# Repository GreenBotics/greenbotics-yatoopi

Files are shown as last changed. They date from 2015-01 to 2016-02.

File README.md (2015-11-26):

## yatoopi (pronounced 'jɑ-tu-pe' )



> aka: Yet another aquaponics project 

## Overview :

Here you will find all the files for this project:
cad, documentation, blog etc

### The aims are :

- open source
- low cost
- somewhat beginner friendly (I am one too)
- maximising re-use (for example I have a box
of 10 or so relatively small dc motors I intend to reuse for various purposes).
- use 3d printing "in a somewhat inteligent manner" : 
this means using it in a lot of cases where repeatable, cheap , reproductible, small /med run
of parts are needed, but not "forcing" its use either
- explore what is possible without massive amounts of store-bought equipment
- not reinvent the wheel whenever possible : I explore, test, modify, other people's
designs whenever possible
- "eco friendly"
- "self sufficient"
- note the quotes around the last two...

FYI , this whole thing is still in the very early stages, but for ONCE, I really
do not want to do documentation 2 years after I am fed up with a project: remember: 
"release early, release often, and DOCUMENT you efforts are least a bit".

## Sub pages etc

[testing](../master/docs/testing.md)

## Grow bed etc

 - the grow bed is build with wood and 3d printed parts
 - while not strictly necessary (you can build grow beds without 3d printing), 
 all the parts used either makes building easier, cheaper, or more practical.
 Also, they offer some esthetic/security benefits (rounded corners etc)
 
 Another important aspect of 3d printed parts: they can be build identically ,
 regardless of your tooling, as long as you have a 3D printer.
 
## cad files (3d printed)

  - for the [grow bed](../master/cad/growbed) (printed corners, assembly helpers)
  - for the [piping](../master/cad/piping) (outflow/drain and media guard )

assembly guides, pictures etc comming soon

## Author:

Mark 'kaosat-dev' Moissette

## LICENSE

GPL until I come up with something better, possibly public domain 

[The GLP License (GPL)](https://github.com/GreenBotics/Automaton/blob/master/LICENSE)

- - -

experimental (http://github.com/badges/stability-badges)

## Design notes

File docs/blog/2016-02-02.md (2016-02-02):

------------------------------------

Title:  Lift-off! Aka: plants are growing!

Author: Mark Moissette 

Date:   2016-02-02 

------------------------------------

##Lift-off!

Planting the (lettuce) seeds took place last week on the 2016-01-27 

![After seeding]
(https://raw.githubusercontent.com/GreenBotics/yatoopi/master/docs/blog/2016-02-02/2016-02-02_00.jpg)

It was done using the following layout

| Lettuce Name | Symbol |
| --- | --- |
| lamb's lettuce | L |
| curly lettuce | C |
| Romaine | R |
| Frisee | F |
| basilicum | B |
| parsley | P |

|---| A | B | C | D | E | F | G | H |
|---|---|---|---|---|---|---|---|---|
| 1 | L | L | L | R | R | C | P | P | 
| 2 | L | L | L | R | R | | | | 
| 3 | L | L | L | R | R | | | | 
| 4 | L | L | L | R | R | C | B | B | 

### Good news :

* The romaine already sprouted after less than **4** days. 
* Power consumption is hovering at around **115 W** for the system (lamps + water pump + air pump),
so this means this can possibly be covered by even a simple solar pannel setup

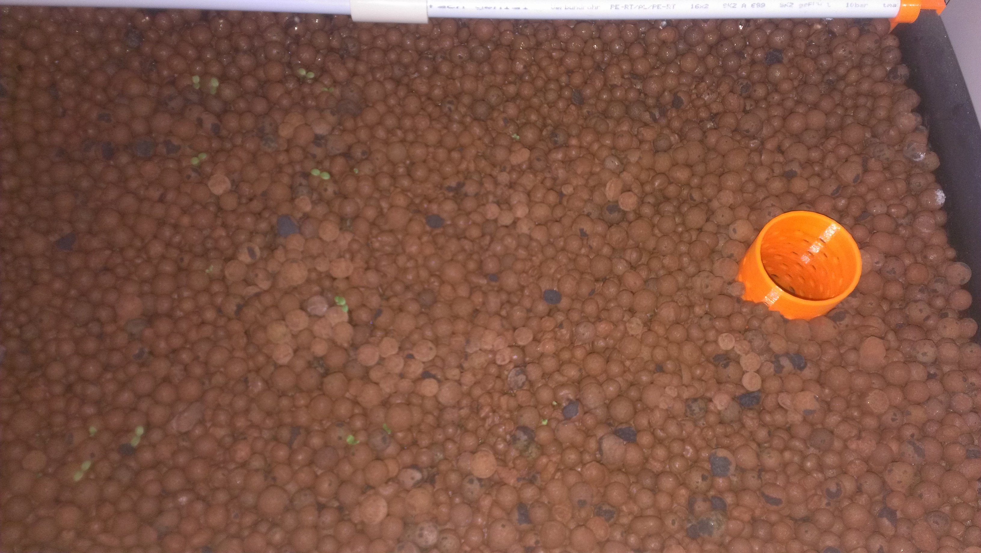
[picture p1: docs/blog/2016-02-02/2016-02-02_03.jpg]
6 days after (in bad lighting

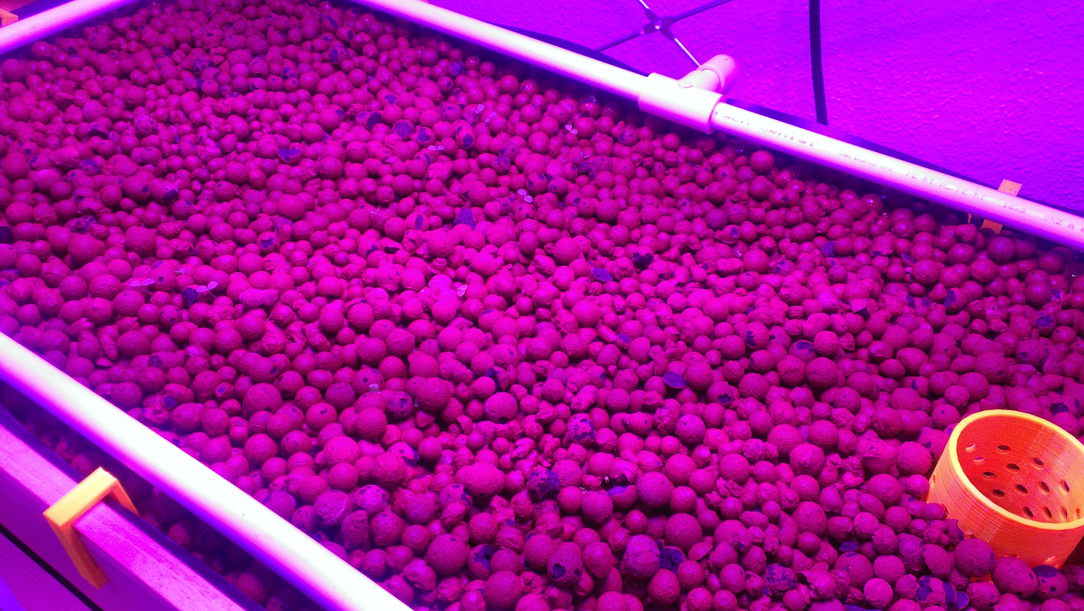
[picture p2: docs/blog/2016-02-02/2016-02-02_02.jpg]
6 days after (the leaves are there, but barely visible


### The less good news: 

* I still have not completed the automated monitoring system (temperature, humidity, water depth in tank, wide angle camera), 
so detailed environemental tracking will not be available from the start , but given that this is an indoor setup, variations 
in the parameters should be minimal
* I have also attempted to install a basic Raspberry Pi + Webcam setup to have some nice remote viewing/timelapse capabilities, but the **very** cheap webcams I have , have very limited view angle, which makes them close to useless

### Next steps:

* watching things grow and going "this rocks, what an amazing level of growth" everyday !
* I have started to look into reusing an old ultrasonic sensor I have for the fishtank water level measurement 
* The [Arducam](http://www.arducam.com/)[ + Esp8266 combo](http://www.arducam.com/tag/arducam-esp8266/) also seems **very** interesting to say the least (even more so as you can more easilly change lenses, switching to a wide angle one) than with a basic webcam / RaspiCam
* I also **DO** intend to finish a basic version the monitoring setup's software side as soon as possible (whenever that might be)

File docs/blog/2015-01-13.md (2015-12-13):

## Airlift pump, first success

#### 2015 Jan 13

So , finally got around to testing of **model A0** *

- raw data
  0.10 L in 6 mins 28,37s 

  ie 0.10L in 388.37s aka 0.015 / min aka 0.92L /h
  
  //old stuff : 6.47283333 mins => 0.0154 L * min-1

- notes: 
  first sucessfull & reproducible test, other air pump (P1 , 100L/H) seems to be half dead
  (ie even attaching a simple bubbler and putting it in water hardly produces any air bubbles)

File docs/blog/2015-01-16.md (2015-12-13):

##  Airlift pump, continued

#### 2015 Jan 16

#### Seperation of concerns etc

one very interesting aspect of airlift pumps is that it allows me to test
their 2 "parts" seperatly:

- the air pump
- the airlift system / pressure chamber

For the first phase of testing, I decided to use commercial (aquarium) air pumps
and see what results I can get : this allows a validation of the airlift system
without worrying about insuficient air pressure.

aka, science : it makes sense !

I tested with 16 mm pipes and the printed ##XXXX

Tested with 200L/h Eheim air pump

Result : 0.1 L in 2 mins 18.22 seconds 

So 0.1 L in 138.22 s aka 0.043 L / min aka 2.6 L per hour

Not so great in absolute terms but keep these things in mind : 

- the water is lifted 60 cm withouth any problems
- the whole plumbing is a prototype which means the joints are waterproof etc

#### Lobe pumps etc:

I also started researching some of the formulas behind lobe pumps
and creating the basics of a parametric design in .

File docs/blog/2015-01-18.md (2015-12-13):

## Airlift pump, continued (3)

#### 2015 Jan 18

I tested with 6 mm tube and the printed ##XXXX 

Tested with 200L/h Eheim air pump with **both outlets
set to 50l/h** : I had to reduce it to minimal levels
as anything over 50 L/h would result in a lot of bubbles but no water being pumped.

Result : 0.05 L in 3 mins 28.46 seconds 

So 0.05 L in 208.46 s aka 0.015 L / min aka 0.86 L per hour

...worst one so far

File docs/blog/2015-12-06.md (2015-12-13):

##Upgrades, reboot etc

After a big failure last summer (most plants died) the grow system never really took off:

So here are steps to get everything (finally ?) going :

- switch to a more powerfull, WATER pump : airlift pumps are really great, but 
are not good enough with so little water depth (around 25 cm max in the current setup)
and are thus too sensitive to water level variations

- actually install a bell (or other) symphon system : this means changing most of the 3d printed plumbing

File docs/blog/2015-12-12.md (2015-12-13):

##Bell syphon...or not

Verdict after running the bell syphon to a lot of different tests:
 it "works"...sorta:
- extremely finicky
- very limited range of flow rates that correctly triggers it
- outwards flow with this size is never sufficient : a inflow strong enough
to trigger the syphon is also also too much to reduce the water level in the container

This means ...Back to the drawing board!
A more mechanical system, but a less sensitive one seems a better bet

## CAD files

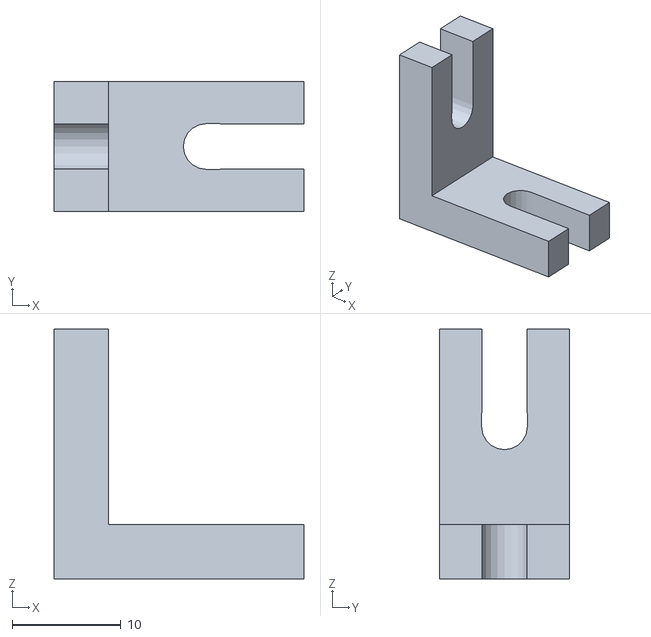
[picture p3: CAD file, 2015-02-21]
cad/growbed/assembly-helpers/BoxAssemblyHelpers.0.0.1.stl
23.0 x 12.0 x 23.0

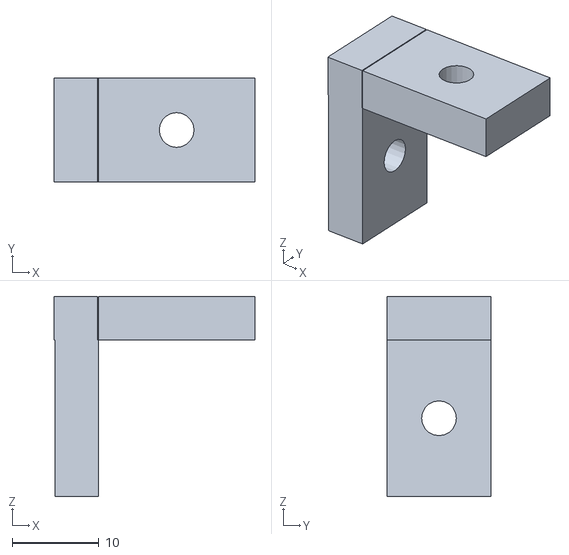
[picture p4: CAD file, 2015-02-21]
cad/growbed/assembly-helpers/BoxAssemblyHelpers.stl
23.1 x 12.0 x 23.0

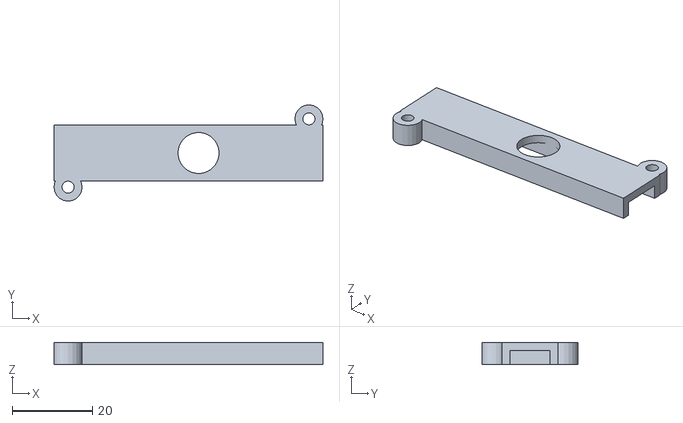
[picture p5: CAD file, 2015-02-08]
cad/accessories/webcam-holder/webcam-holder-top-0.0.1.stl
67.0 x 24.0 x 5.50

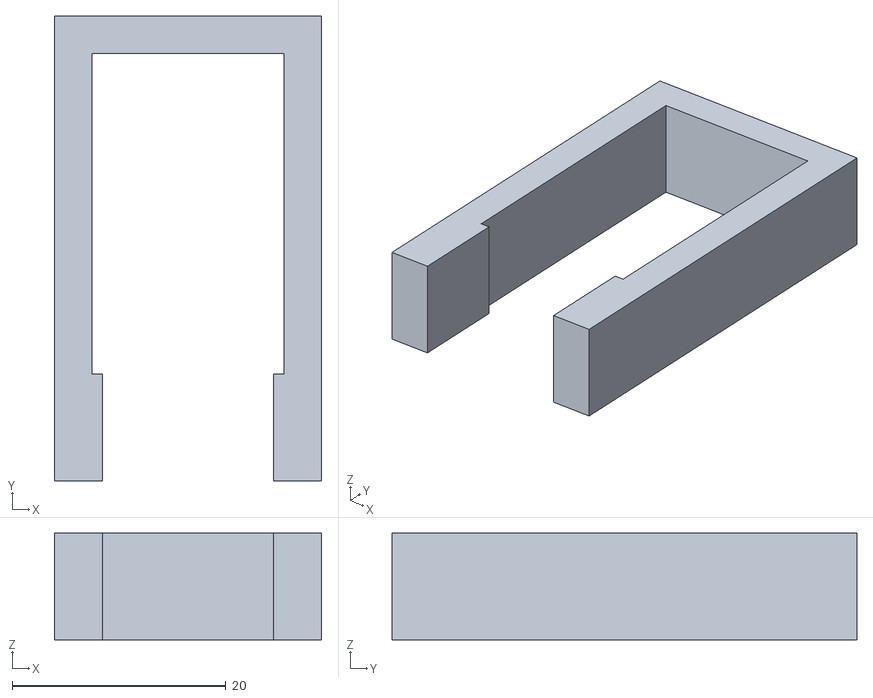
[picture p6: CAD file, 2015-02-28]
cad/growbed/bed-clips/bed-clips.0.0.1.stl
25.0 x 43.5 x 10.0

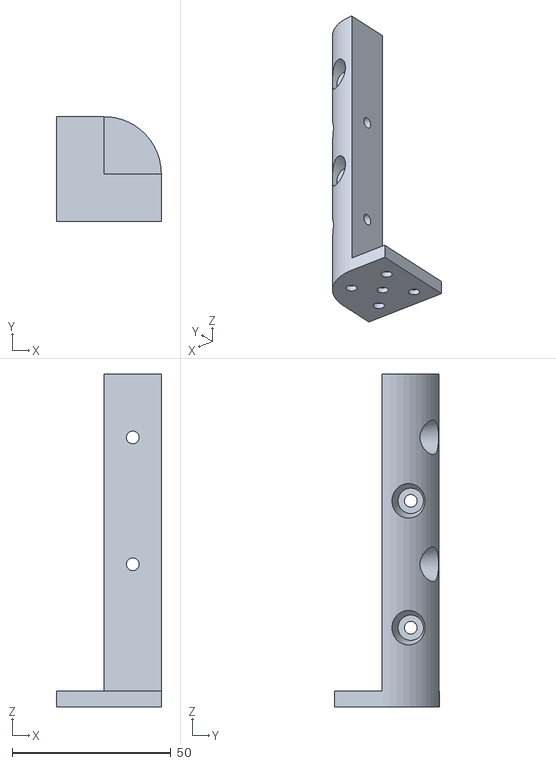
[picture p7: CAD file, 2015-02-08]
cad/growbed/bed-corners/aquaponics-bed-corner-0.0.1.stl
33.0 x 33.0 x 105.0

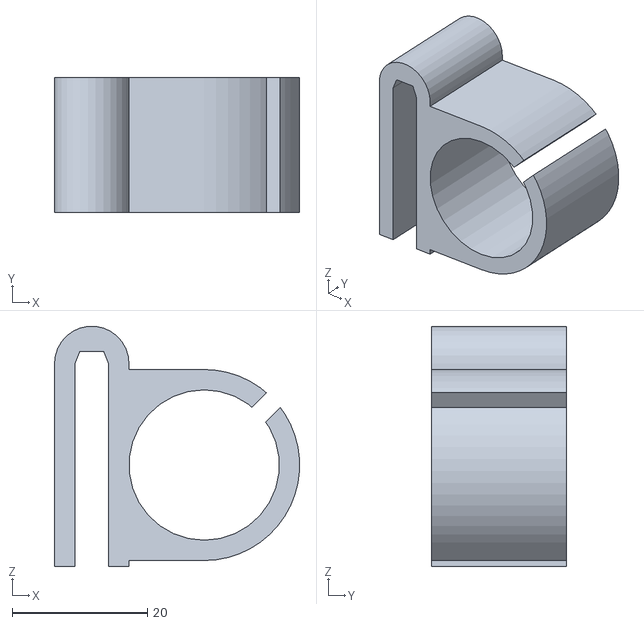
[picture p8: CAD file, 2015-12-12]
cad/piping/aquarium-mounts/sideTubingHolder-m22-0.0.2.stl
36.2 x 20.0 x 35.5

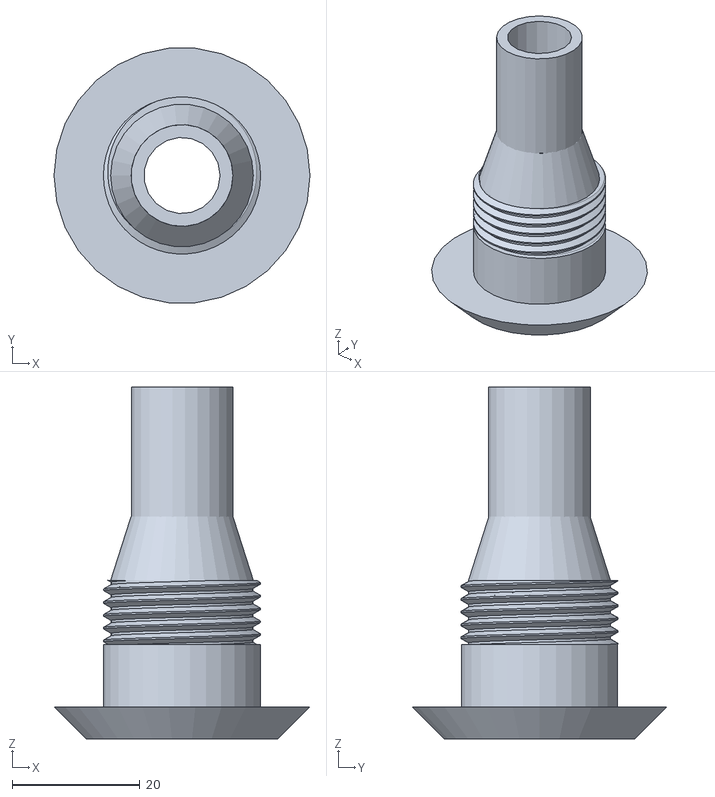
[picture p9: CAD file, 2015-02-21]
cad/piping/hydroponic-drain/hydroponic_drain_0.0.4.stl
40.0 x 39.8 x 55.0

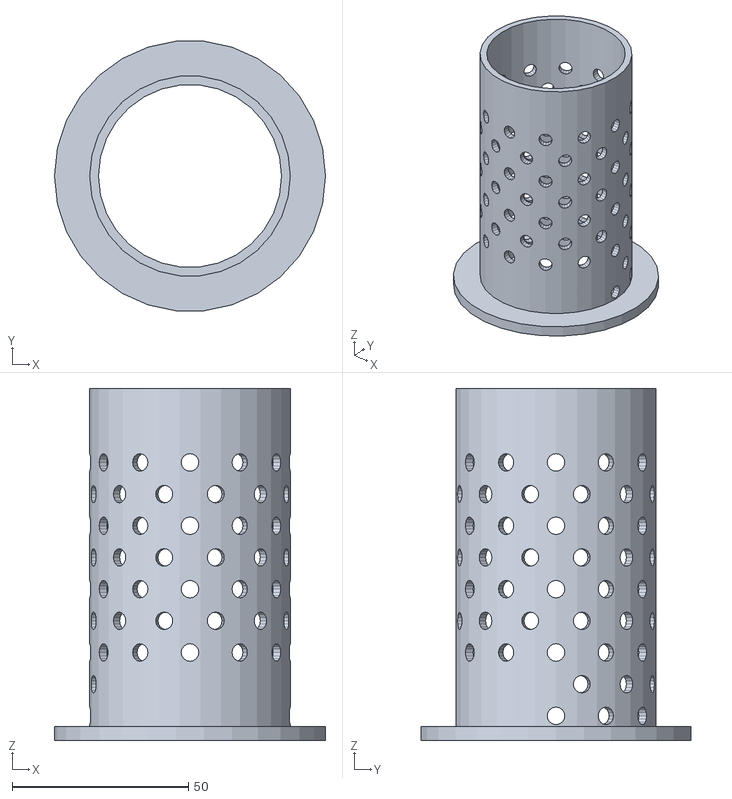
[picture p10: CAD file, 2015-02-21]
cad/piping/media-guard/MediaGuard.0.0.1.stl
77.0 x 76.6 x 100.0

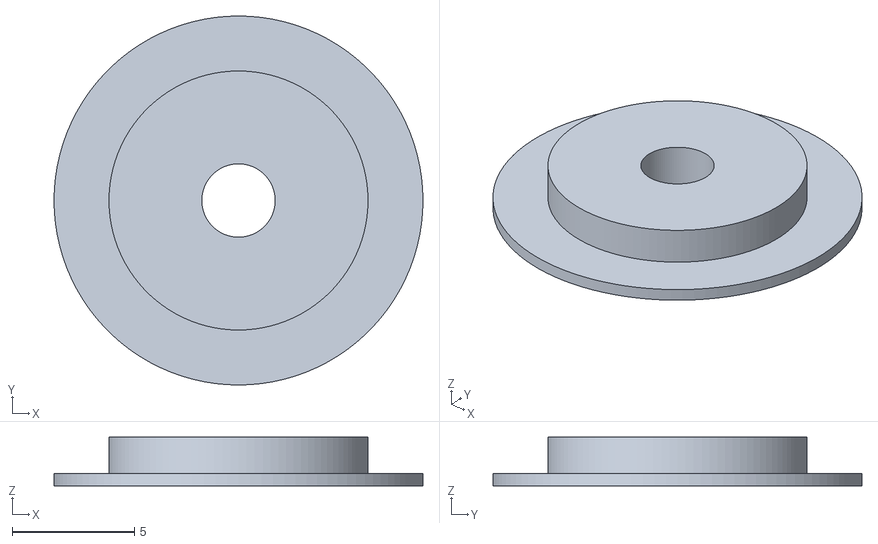
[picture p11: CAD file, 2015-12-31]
cad/piping/syphon-system/custom_syphon_bucket_out_3mm.stl
15.1 x 15.1 x 2.00

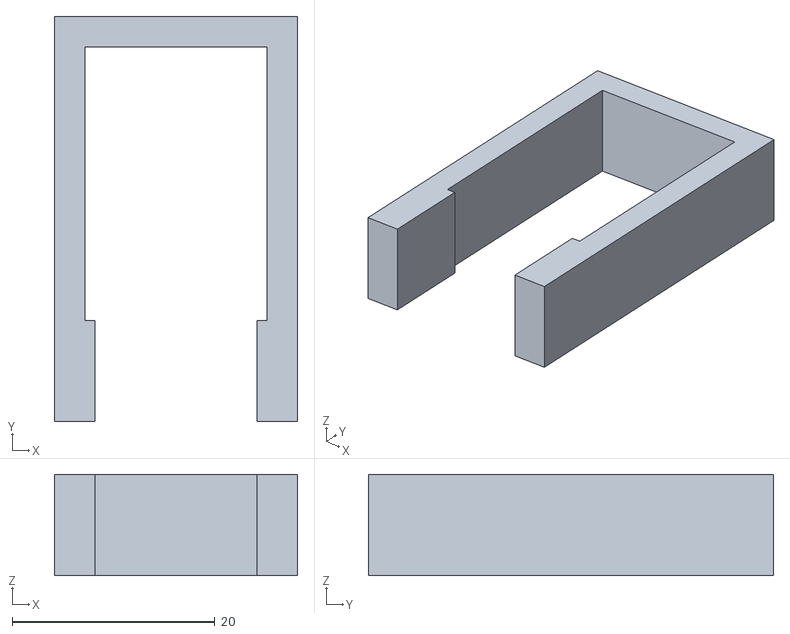
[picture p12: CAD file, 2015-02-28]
cad/growbed/bed-clips/bed-clips.stl
24.0 x 40.0 x 10.0

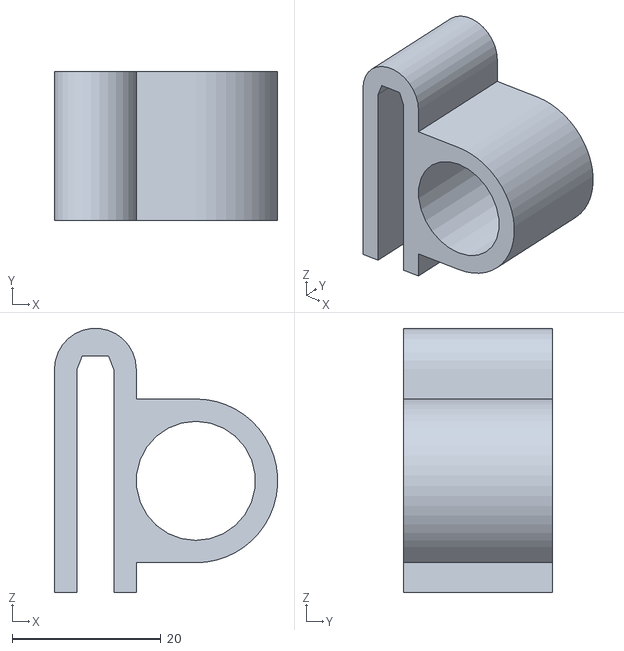
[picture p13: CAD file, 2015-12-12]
cad/piping/aquarium-mounts/sideTubingHolder-m16-0.0.1.stl
30.0 x 20.0 x 35.5

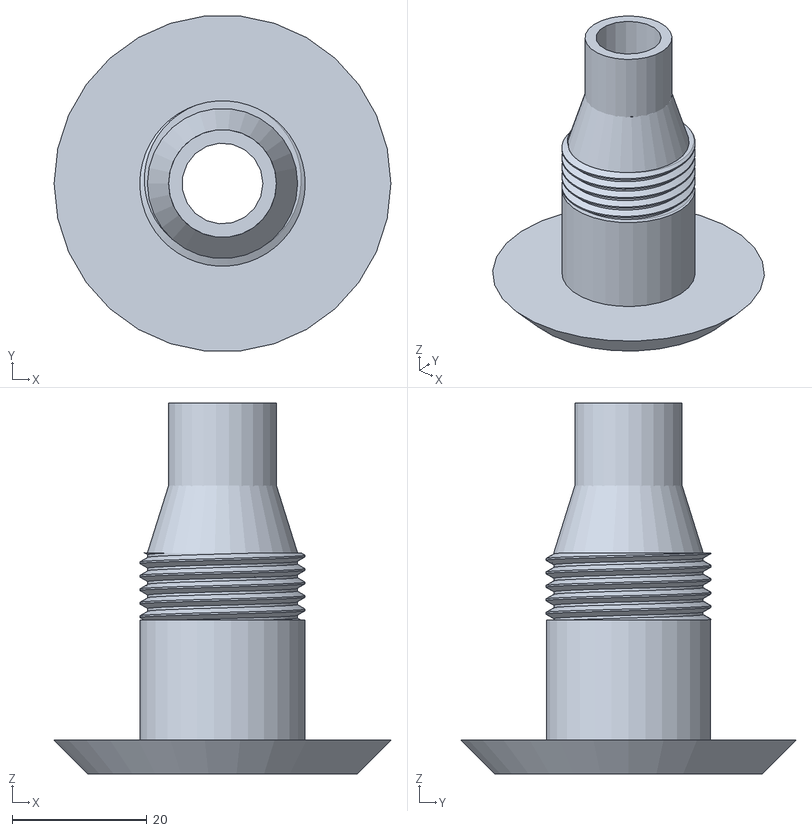
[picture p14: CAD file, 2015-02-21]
cad/piping/hydroponic-drain/hydroponic_drain_0.0.5.stl
50.0 x 49.7 x 55.0

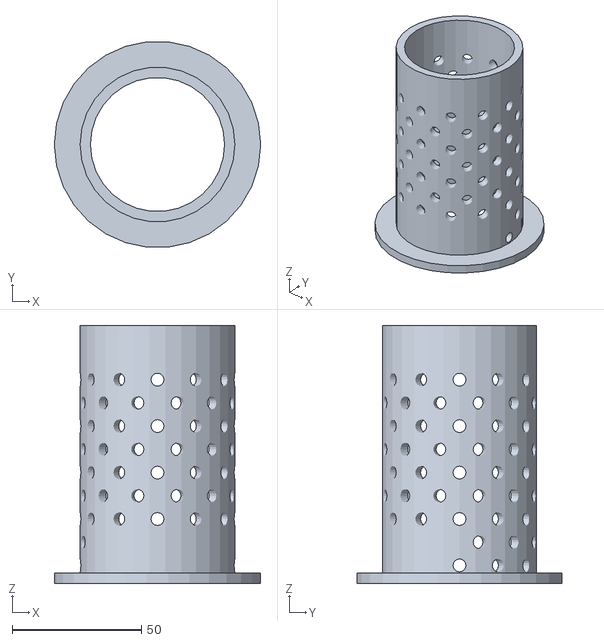
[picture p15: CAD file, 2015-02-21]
cad/piping/media-guard/MediaGuard.stl
80.0 x 79.6 x 100.0

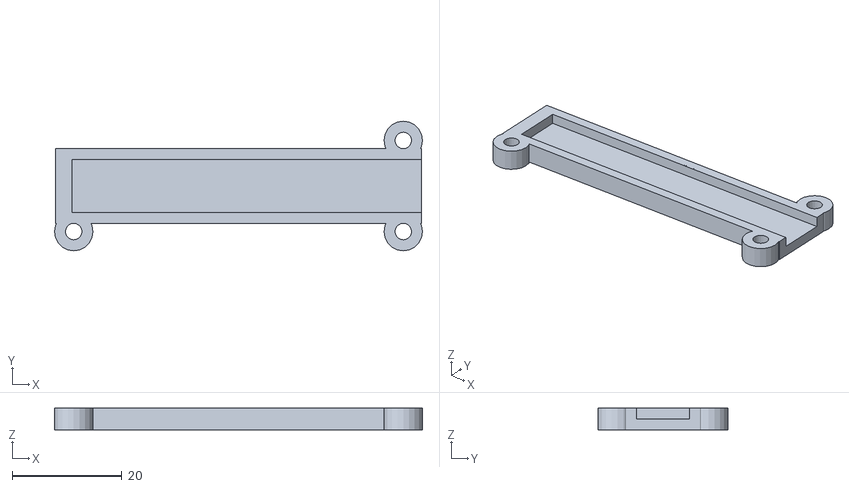
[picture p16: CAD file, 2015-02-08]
cad/accessories/webcam-holder/webcam-holder-bottom-0.0.2.stl
67.0 x 23.6 x 3.98

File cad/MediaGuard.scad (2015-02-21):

// Media guard , to prevent media (clay pellets etc) + roots
//from clogging the outflow

mediaGuard();

module mediaGuard(height=100,innerDia=52,wallSize=4, baseLip=10, baseLipHeight=4, res=30){
  fullDia = innerDia+wallSize*2;
  fudge= 0.1;
  
  bottomNoWaterZoneHeight = 2;//how heigh is the zone withouth holes at the base of the guard
  orientedWaterZoneHeight = 18; 
  orientedWaterZoneAlign  = "front"; //can be "front","back"
  topNoWaterZoneHeight = 10;
  
  holesDia = 5;
  holesRes = 8;
  vertHolesDist = holesDia + 4;
  
  radHolesNb = 12;
  
  module baseHole(length = fullDia){
    rotate([0,90,0]) cylinder(r=holesDia/2,h=length,$fn=holesRes,center=true);
  }
  
  module holes(){
    fullHolesZoneHeight = height - orientedWaterZoneHeight - bottomNoWaterZoneHeight - topNoWaterZoneHeight;
    verHolesNb         = (fullHolesZoneHeight-vertHolesDist) / vertHolesDist;
    layerRot  = (360 / radHolesNb)*1.5;// how much do we rotate holes for each "hole layer" so they are not aligned
    
    //for oriented holes region
    orientedHolesVerNb = orientedWaterZoneHeight / vertHolesDist;
    orientedHolesLength= fullDia/2;
    orientedHolesOffset = orientedWaterZoneAlign == "front" ? fullDia/2 : -fullDia/2;
    orientedHolesLayerRot  = (360 / radHolesNb)*0.5;// how much do we rotate holes for each "hole layer" so they are not aligned
    echo("orientedHolesVerNb",orientedHolesVerNb,"verHolesNb",verHolesNb,"orientedHolesOffset",orientedHolesOffset);
    
    
    //main hole
    translate([0,0,-fudge/2]) cylinder(r=innerDia/2,h=height+fudge,$fn=res);
    
    //all sided holes
    for( j = [0 : verHolesNb ] )
    {
      for ( i = [0 : radHolesNb/2] )
      {
          rotate( i * 360 / radHolesNb + ( j * layerRot ), [0, 0, 1])
          
          translate([0, 0, bottomNoWaterZoneHeight+orientedWaterZoneHeight+holesDia+j*vertHolesDist])
          baseHole();
      }
    }
    
    //oriented (one sided) holes
    for( j = [0 : orientedHolesVerNb-1 ] )
    {
      for ( i = [0 : radHolesNb/2] )
      {
          rotate( i * 360 / radHolesNb + ( j * orientedHolesLayerRot ), [0, 0, 1])
          translate([orientedHolesOffset, 0, bottomNoWaterZoneHeight+holesDia+j*vertHolesDist])
          baseHole(orientedHolesLength);
      }
    }
    
    
  }
  
  difference(){
        union(){
          cylinder(r=fullDia/2,h=height,$fn=res);
          cylinder(r=(fullDia+baseLip*2)/2, h=baseLipHeight);
        }
    holes();
  }
  
  
  
}

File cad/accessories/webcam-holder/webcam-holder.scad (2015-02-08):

//webcamHolder(side="bottom");
webcamHolder(side="top");



module webcamHolder(side="top"){
  fudge = 0.01;
  length = 61;
  width  = 8;
  height = 3.95;
  wallThickess = 2;
  innerClearance= 0.8;
  innerClearanceTopBottom = 0;
  
  camOpticsDia = 10.2;
  camOpticsOffset=28;
  
  mountHolesDia = 2.1;
  mountHoleStartOffset= 7.6;
  mountHolesEndDist = 4;
  
  pcbThickness         = 2;
  pcbFootOutlineHeight = 0.5;
  pcbFootOutlineWidth  = 0.5;
  
  extMountDia = 3;
  
  fullLength = length + ( wallThickess + innerClearance ) *2;
  fullWidth  = width  + ( wallThickess + innerClearance ) *2;
  fullHeight = height + ( wallThickess + innerClearanceTopBottom ) *2;
  
  innerLength = length + ( innerClearance ) *2;
  innerWidth  = width  + ( innerClearance ) *2;
  innerHeight = height + ( innerClearanceTopBottom ) *2;
  
  pcbFootWidth  = width   - pcbFootOutlineWidth*2;
  pcbFootLength = length - pcbFootOutlineHeight*2;
  pcbFootHeight = 3;
  
  echo("fullHeight",fullHeight);
  
  res=50;
  
  
  difference(){
  
    union(){
    
      difference(){
        cube(size=[fullLength, fullWidth, fullHeight],center=true);
        translate([wallThickess, 0, 0])  cube(size=[innerLength+wallThickess, innerWidth, innerHeight],center=true);
        
        translate([length/2-camOpticsOffset, 0, -fudge]) #cylinder(r=camOpticsDia/2,h=fullHeight/2+fudge,$fn=res);
      };

      
      //pcb outline "feet"
      /*translate([0,0,-innerHeight/2+pcbFootOutlineHeight/2]) 
      difference(){
        cube(size=[length, width, pcbFootOutlineHeight],center=true);
        cube(size=[pcbFootLength, pcbFootWidth, pcbFootOutlineHeight],center=true);
      }
      translate([0,0,-innerHeight/2+pcbFootOutlineHeight/2+pcbThickness]) 
      difference(){
        cube(size=[length, width, pcbFootOutlineHeight],center=true);
        cube(size=[pcbFootLength, pcbFootWidth, pcbFootOutlineHeight],center=true);
      }
      */
      
      
      //bolt mount stuff
      translate([30,(fullWidth+extMountDia)/2,0]) mount( od= extMountDia+wallThickess*2, id=extMountDia, h=fullHeight);
      translate([30,-(fullWidth+extMountDia)/2,0]) mount( od= extMountDia+wallThickess*2, id=extMountDia, h=fullHeight);
      
      translate([-30,-(fullWidth+extMountDia)/2,0]) mount( od= extMountDia+wallThickess*2, id=extMountDia, h=fullHeight);
    }
  
    //TODO: UGH openscad old version : no real variables, asignments etc 
    //cutoffset = -3;
    if(side == "top")
    {
      translate([0,0,-3]) #cube([100,50,6],center=true);
    }
    if(side == "bottom")
    {
      translate([0,0,3]) #cube([100,50,6],center=true);
    }
    
    
  }
  
  //pcb foot : should not be cut in half
  if(side == "top"){
    translate([-length/2+1.5,0,+pcbFootHeight/2]) 
    cube(size=[3, innerWidth, pcbFootHeight],center=true);
  }
}


module mount(od=5, id=3, h=10,res=20){

  difference(){
      cylinder(r=od/2,h=h,$fn=res,center=true);
      cylinder(r=id/2,h=h,$fn=res,center=true); 
  }

}

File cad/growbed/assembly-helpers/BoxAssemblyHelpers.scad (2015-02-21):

// An L shaped wooden box assembly / screwing helper

assemblyHelper();

module assemblyHelper(plankThickness=18,screwDia=4,wallSize=4,thickness=5){

  height = plankThickness;
  width    = wallSize*2 + screwDia;
  fudge= 0.1;
  
  module side(){
      difference(){
        translate([height/2-thickness/2,0,thickness/2]) cube([height+thickness,width,thickness],center=true);
        
        
        translate([height/2,0,0]) 
          hull(){
            cylinder(r=screwDia/2+fudge,h=thickness+fudge,$fn=20);
            translate([0,-(screwDia+fudge)/2,0])cube([height/2,screwDia+fudge,thickness+fudge]);
          }
      }
  }
  
  rotate([0,-90,0]) union(){
    side();
    rotate([0,90,0]) translate([0,0,-thickness]) side();
    //translate([-thickness-0.1,-width/2,0]) cube([thickness,width,thickness+fudge]);
  }
}

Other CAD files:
cad/accessories/webcam-holder/webcam-holder-top.stl
cad/growbed/bed-corners/aquaponics-bed-corner-0.0.2.stl
cad/piping/syphon-system/custom_syphon_bucket_out_1mm.stl
cad/growbed/bed-corners/aquaponics-bed-corner.stl
cad/growbed/bed-clips/bed-clips.scad
cad/accessories/webcam-holder/webcam-holder-top-0.0.1-test.stl
cad/accessories/webcam-holder/webcam-holder-top-0.0.2.stl
cad/growbed/bed-corners/aquaponics-bed-corner.scad
cad/piping/aquarium-mounts/aquariumMounts.scad
cad/piping/aquarium-mounts/cornerTubingHolder-0.0.1.stl
cad/piping/aquarium-mounts/sideTubingHolder-m22-0.0.1.stl
cad/piping/hydroponic-drain/hydroponic_drain.scad
cad/piping/hydroponic-drain/hydroponic_drain_nut.scad
cad/piping/hydroponic-drain/hydroponic_drain_nut_0.0.5.stl
cad/piping/hydroponic-drain/hydroponic_stand_pipe.scad
cad/piping/hydroponic-drain/threads.scad
cad/piping/media-guard/MediaGuard.scad
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

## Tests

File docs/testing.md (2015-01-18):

Pump and airlilft designs testing
=================================

###Goals

  For now , for an indoor, relatively small setup : 
  
  - 60 L aquarium, fish species not decided yet, could be too small for Tilapias
  - 80 x 40 X 10 aprox grow bed, home built, wood & 3d printed parts: more on this later
  - two 13w neon tubes (bathroom variety, will post more specs)
  - aquarium is 60 cm below the grow bed, so any pumping system needs to be able to lift water up to that height *at least*

#Pumps

Bought Pumps 
------------

- 3W air pump  : 60L / h (id: P0)
- 6W air pump  : 100L /h (id: P1) **KO**
- 3.5W air pump: 200L /h (id: p2) 

Pump Id  |  Pump type   |  Power rating(W) | Works? | Air/Water flow L/h | Price (e) | ref 
---------|--------------|----------------  |--------| -------------------| --------- | ---
P0       |    air       |  3               | yes    |   60               | N/A       | N/A
P1       |    air       |  6               | no     |   100              | N/A       | N/A
P2       |    air       |  3.5             | yes    |   200              | 30        | N/A

Built pumps
-----------

- nothing conclusive so far, work in progress
  
Airlift pump designs
---------------

  > **What is an airlift pump ? **
  > http://en.wikipedia.org/wiki/Airlift_pump 

Found following designs:

- Conduit with Hole 
by 3Dponics http://www.thingiverse.com/thing:400341 (id: A0)
- Airlift pump - air powered water pump
by gswatts, http://www.thingiverse.com/thing:515591 (id: A1)
- Parametric Airlift Water Valve
by relet http://www.thingiverse.com/thing:14230 (id: A2)
- Water pump driven by air
by bqzero http://www.thingiverse.com/thing:609739 (id: A3)

  > **Note:**
  > I do not support, condone the policies of, or like Makerbot & thus Thingiverse in any form or way,
  > but sadly, I was not able to find designs in any other 3d printable design repositories...

So to recap (tables are easier to read or something ?)

Airlift design Id  |  Airlift design name                       | design link   | Designer |  License  |
------------------ | --------------------------------------     | --------------| -------  |  -------- |
A0                 |  Conduit with Hole                         | http://www.thingiverse.com/thing:400341 |  3Dponics | CC-BY-NC-SA
A1                 |  Airlift pump - air powered water pump     | http://www.thingiverse.com/thing:515591 |  gswatts  | CC-BY-SA
A2                 |  Parametric Airlift Water Valve            | http://www.thingiverse.com/thing:14230  |  relet    | CC-BY-SA
A3                 |  Water pump driven by air                  | http://www.thingiverse.com/thing:609739 |  bqzero   | CC-BY-NC-SA

Test results
-------------

  > **Note:**
  > All Tested pumps can be found [here](#pumps) 

Airlift design   | Pump Model   | Pumping height (m) | Works? | Water flow L/h
-------------    | -------------| --------------     | -------| ---------
A2               | P0           | 0.6                |  yes   | 0.92
A3               | P0           | 0.6                |  no    | 0
A3               | P2           | 0.6                |  yes   | **2.6**

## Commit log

2015-01-18 - added additional blog posts (now under different folder) - cleaed up testing notes file, added data about aditional pumps & testing
2015-02-08 - added scad & stl files for: * growbed corners * webcam holder (infragram camera)
    [aquaponics-bed-corner-0.0.1.stl, aquaponics-bed-corner-0.0.2.stl, aquaponics-bed-corner.scad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]
2015-02-21 - added scad & stl files for: * heavilly modified hydroponic drain (original by Vik Oliver) * BoxAssembly helpers (screw guide helper for assembly) * MediaGuard
    [BoxAssemblyHelpers.0.0.1.stl, BoxAssemblyHelpers.scad, BoxAssemblyHelpers.stl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]
2015-02-21 - restructuring of cad folder/file structures
    [BoxAssemblyHelpers.0.0.1.stl, BoxAssemblyHelpers.scad, BoxAssemblyHelpers.stl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]
2015-02-21 - updated readme with basic information about cad files and assembly
2015-02-28 - added cad files for bed clips - updated readme & added license
    [bed-clips.0.0.1.stl, bed-clips.scad, bed-clips.stl]
2015-05-24 - added basics of aquarium mounts for various tubings
    [aquariumMounts.scad]
2015-05-24 - finished first pass of cornerTubingHolder, & generated stl for first print - more work done on other tubing elements
    [aquariumMounts.scad, cornerTubingHolder-0.0.1.stl]
2015-12-12 - tweaks and adjustements to aquariumMounts
    [aquariumMounts.scad]
2015-12-12 feature(sideTubeHolder): added missing stls for sideTubingHolders
    [sideTubingHolder-m16-0.0.1.stl, sideTubingHolder-m22-0.0.1.stl, sideTubingHolder-m22-0.0.2.stl]
2015-12-12 feature(stand_pipe): added experimental stand pipe design
    [hydroponic_stand_pipe.scad]
2015-12-12 feature(bell-syphon): added experimental bell syphon
    [bell_syphon_0.0.1.stl, syphon.scad]
2015-12-13 refactor(): moved syphon related code & stls to seperate folder
    [bell_syphon_0.0.1.stl, syphon.scad]
2015-12-13 feature(): started work on custom syphon - also renamed old bell syphon explicitely to bell_syphon.scad
    [bell_syphon.scad, custom_syphon.scad]
2015-12-19 feature(custom-syphon): - fleshed out & cleaned up all of the components of the syphon - started adding elements of overall parameter based computation of various in/outflow holes etc
    [custom_syphon.scad]
2015-12-22 feature(syphon): - cleaned up valve & hinge - merged base with main container - lots of minor tweaks, cleanups, improvements
    [custom_syphon.scad]
2015-12-26 feature(syphon): further improvements to syphon : - better "slide in" wall for modular flow system - overall tweaks and improvements
    [custom_syphon.scad]
2015-12-28 feature(syphon): - fleshed out "modular wall" - fixed centering issue for "middle wall" of container - various other tweaks and adjustments
    [custom_syphon.scad]
2015-12-29 feature(syphon): lots of adjustements after initial prints - reduced outer diameter - added extra clearance between bucket and container - increased diameter of hinge (internal) - redid most of the h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
    [custom_syphon.scad]
2015-12-29 feature(syphon: binaries): - added missing binaries (stl files) for syphon pieces
    [custom_syphon_bucket.stl, custom_syphon_container.stl, custom_syphon_spout_wall.stl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]
2015-12-29 feature(syphon): - more minor improvements & tweaks to container - generate binary(stl) for container & printed out : so far so good
    [custom_syphon.scad, custom_syphon_container.stl]
2015-12-30 feature(syphon): - adjusted parameters and cleaned up spout wall & valve - regenerated stls
    [custom_syphon.scad, custom_syphon_spout_wall.stl, custom_syphon_valve.stl]
2015-12-30 feature(syphon): - updated, fixed & cleaned up bucket
    [custom_syphon.scad, custom_syphon_bucket.stl]
2015-12-30 feature(syphon): - tweaked valve
    [custom_syphon.scad, custom_syphon_valve.stl]
2015-12-30 feature(syphon): - tweaked, fleshed out hinge center - generated stl files
    [custom_syphon.scad, custom_syphon_hinge_center.stl, custom_syphon_hinge_lever.stl]
2015-12-31 feature(syphon): - created output adapter for bucket - generated various preset stls
    [custom_syphon.scad, custom_syphon_bucket_out_1mm.stl, custom_syphon_bucket_out_3mm.stl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]
